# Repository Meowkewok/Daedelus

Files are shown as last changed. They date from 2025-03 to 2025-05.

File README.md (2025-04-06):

# DAEDELUS
Designed by: @Meowkewok
A 3d printer designed by a High School student for Hack Club's Infill.  
## Features
- 310mm3 Print area
- Sherpa Mini Extruder (Direct Drive)
- Under $400
- Heated bed
## Additional Info
Link to Daedelus on the Hack Club Infill site: https://infill.hackclub.com/printers/daedelus/
There is a detailed log with progress and useful info about this in the JOURNAL.MD file  
Link to BOM- https://docs.google.com/spreadsheets/d/1hZlX8M_wxNlEcmAArnw9ARre6T5sTla1MoFUZHyh3DU/edit?usp=sharing  
Link to CAD: https://a360.co/3XCGgpZ   
Thank you so much @dari // alexren for this amazing program!

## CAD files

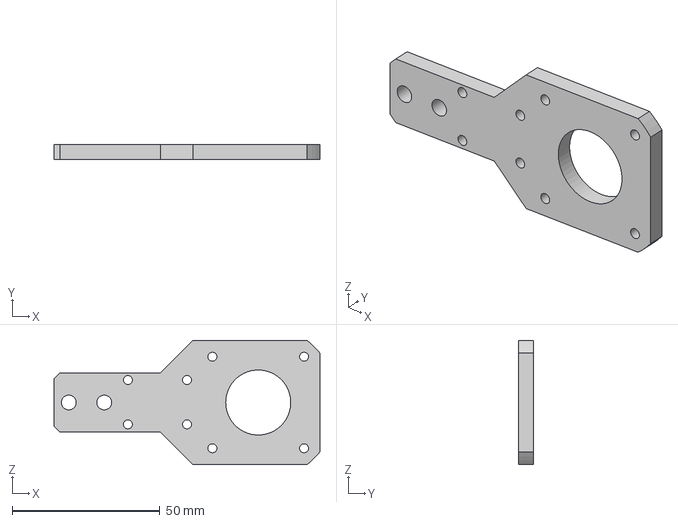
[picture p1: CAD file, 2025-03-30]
CAD/X to Z Mount (NEMA17).step
90.0 x 5.00 x 42.0 mm

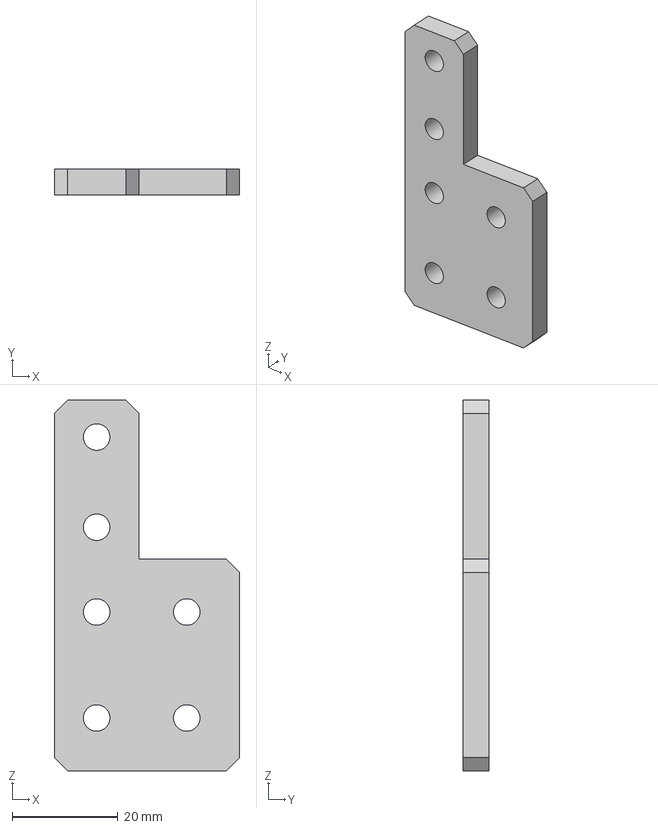
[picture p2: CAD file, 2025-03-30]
CAD/2040 to 2020 Bracket.step
35.0 x 5.00 x 70.0 mm

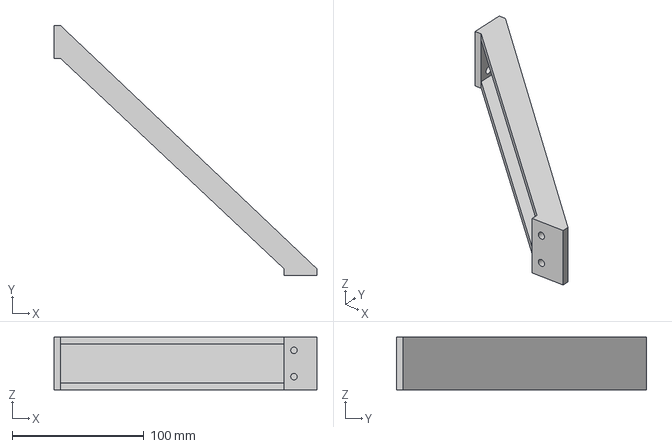
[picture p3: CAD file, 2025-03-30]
CAD/Corner Bracket.step
200.0 x 190.0 x 40.0 mm

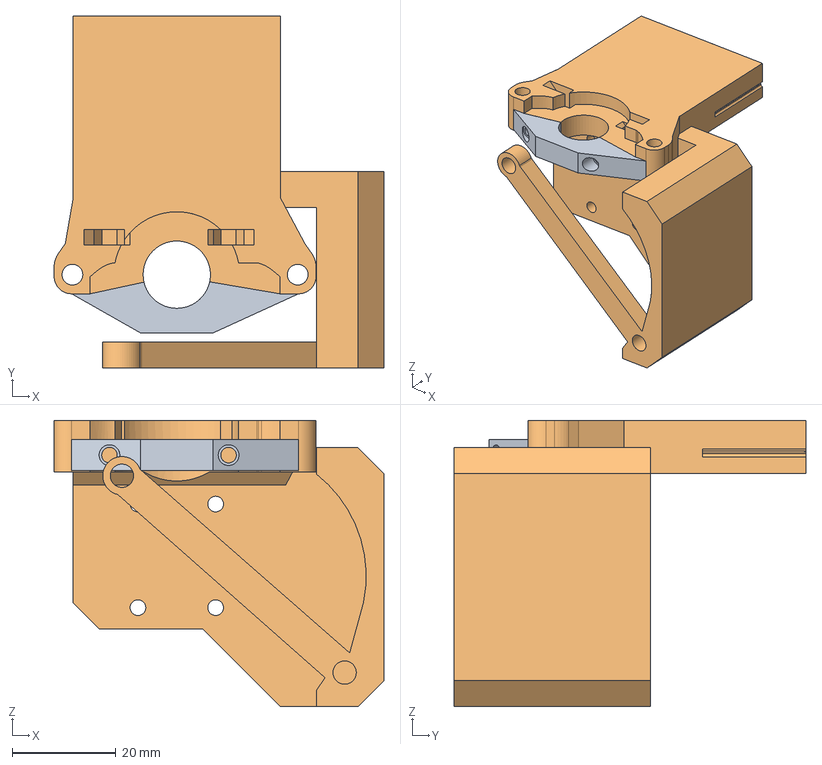
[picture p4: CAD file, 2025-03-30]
CAD/Extruder Mount.step
63.7 x 68.0 x 55.3 mm

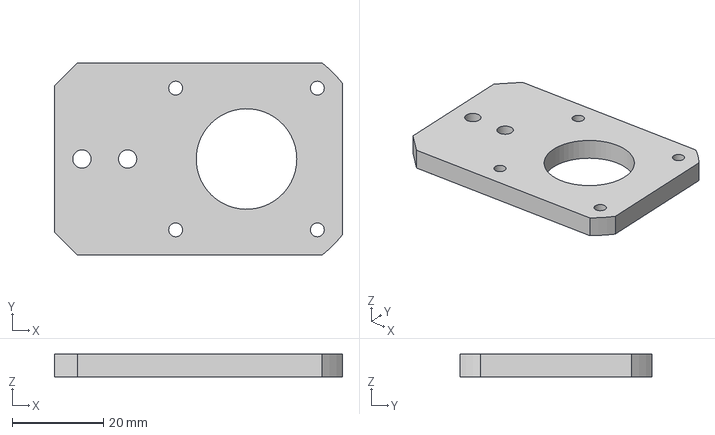
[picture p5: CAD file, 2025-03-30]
CAD/NEMA17 To 20XX Extrusion.step
63.0 x 42.0 x 5.00 mm

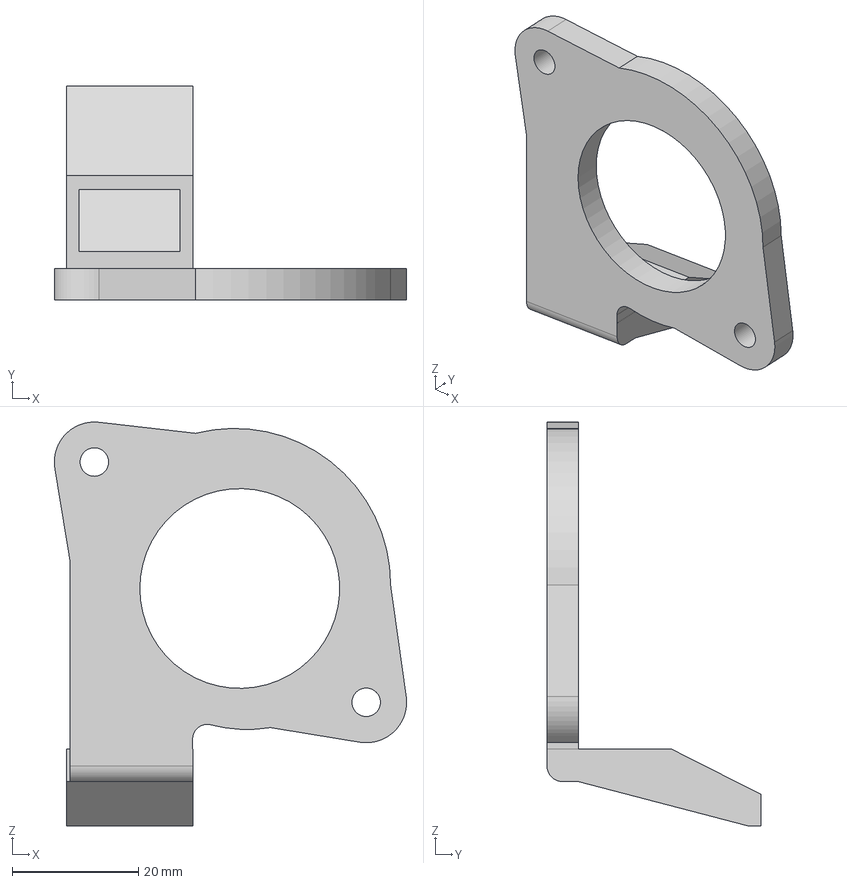
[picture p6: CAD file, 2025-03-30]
CAD/Part Cooling Duct.step
55.7 x 33.9 x 63.9 mm

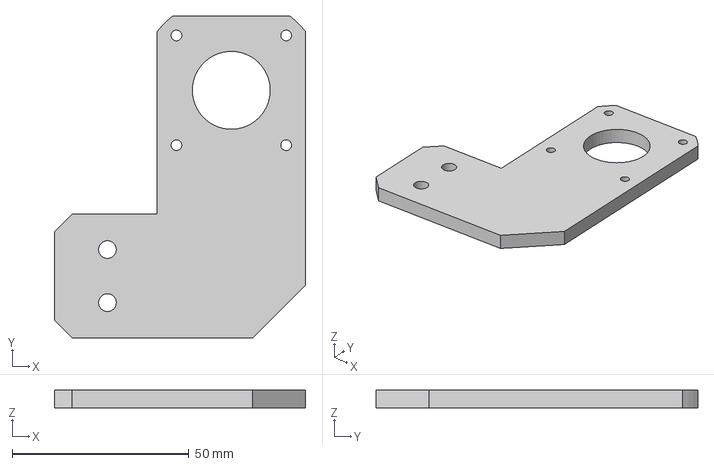
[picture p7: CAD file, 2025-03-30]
CAD/Corner Nema Bracket.step
71.0 x 91.0 x 5.00 mm

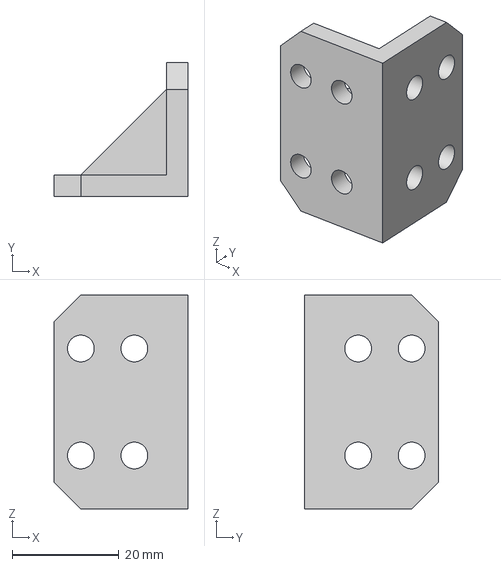
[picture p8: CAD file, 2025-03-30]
CAD/2040 Connection Bracket.step
25.0 x 25.0 x 40.0 mm

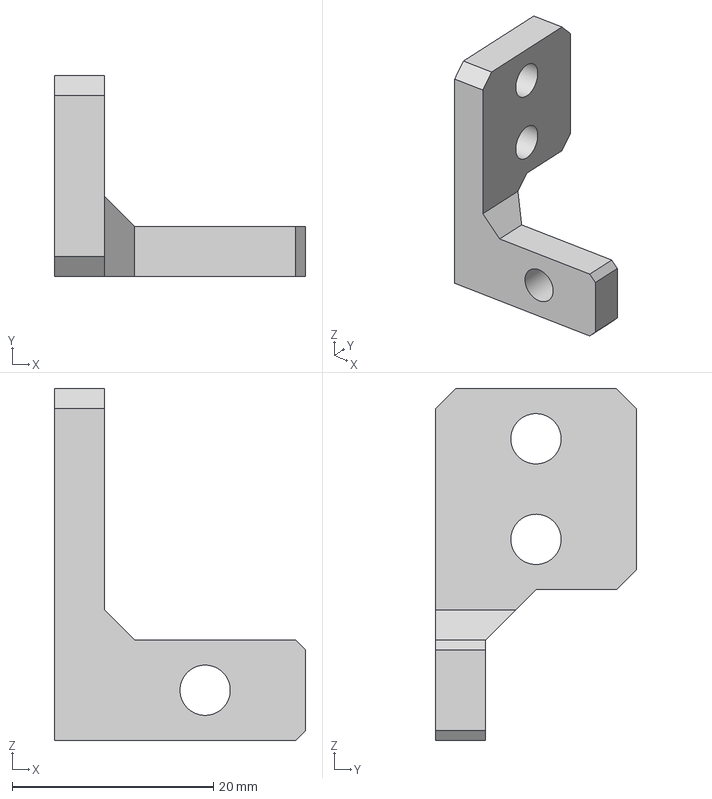
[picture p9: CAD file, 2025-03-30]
CAD/Y Axis Idler Holder.step
25.0 x 20.0 x 35.0 mm

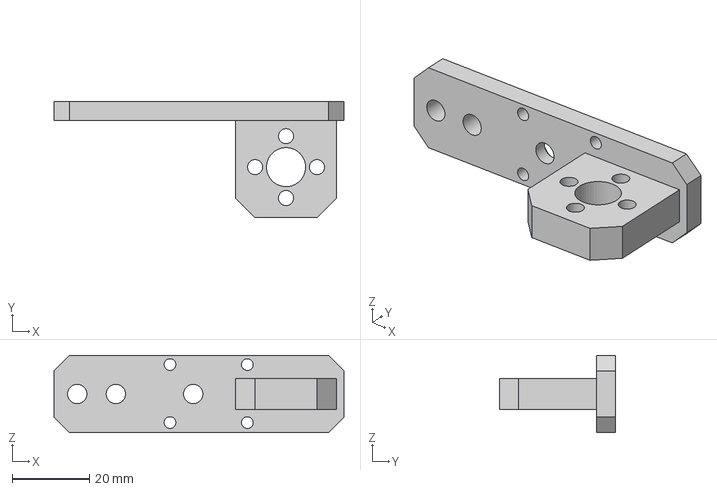
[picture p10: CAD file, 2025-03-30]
CAD/X to Z Mount (Lead Screw).step
75.0 x 30.1 x 20.0 mm

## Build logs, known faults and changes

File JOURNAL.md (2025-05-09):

# Daedelus

Made by: @Meowkewok  
Repository link: https://github.com/meowkewok/Daedelus  
Total hours so far: 42.5   

- [x] I have a 3D printer or will be getting one before March 21st

Daedelus was a Greek inventor, builder, and tinkerer, hence the name.  
I started this project with a coreXY design, but I flew too high, hence the name/designation Daedelus (Icharus) for the first variant.

## Link to CAD: 
https://a360.co/3XCGgpZ

## New Design Goals:
- [x] $400 (USD) (to buy all parts new, w/o shipping or tax)
- [x] 310mm3 Build Volume
- [x] Cartesian Bedslinger
- [x] Cool design
- [x] Touchscreen UI
- [ ] ~~Klipper w/ RPi?~~

## BOM
I just decided to make a spreadsheet using Google Sheets, it was easier. LINK: https://docs.google.com/spreadsheets/d/1hZlX8M_wxNlEcmAArnw9ARre6T5sTla1MoFUZHyh3DU/edit?usp=sharing

## Log
|Date |Task |Time |Notes|
|-----|-----|-----|-----|
|2/21/2025|Set up Repo, ideas, design goals, began BOM, began CAD|4 Hours|Thanks to my brain for finally deciding what to make|
|2/23/2025|CAD, Research|3 hours||
|2/26/2025|Bit more BOM|30 mins|Buying cheap parts from China|
|2/27/2025|Bit more BOM, some research|1 Hour||
|2/28/2025|Tons of CAD!|3 Hours|Finished the XY gantry!, started Z axis/frame|
|3/6/2025|More CAD! Also made a belt routing pic|2 Hour|Worked on frame|
|3/10/2025|BOM|1.5 Hours|Got it down a tad, have more to do...|
|3/15/2025|CAD, Research, BOM|1.5 Hours|Started Redesign|
|3/16/2025|CAD, BOM|3 Hours|Finished XY axis|
|3/17/2025|BOM, CAD|2.5 Hours|Started toolhead mount|
|3/25/2025|CAD|1 Hour|almost done!|
|3/26/2025|CAD|30 mins||
|3/27/2025|CAD, Logo|2 Hours|Yay logo, also almost done again!|
|3/30/2025|CAD, BOM|2 Hours|I think im done!|
|4/3/2025|CAD, Fixing Journal|1 Hour||
|4/5/2025|CAD, Fixing Journal|1 Hour||
|4/6/2025|CAD|2 Hours|Made a toolhead swapper?|
|4/15-18/2025|Ordering parts|5 hours|i hate amazon so much|
|4/21/2025|Got parts, started assembling|4 Hours|YAY PARTS|
|4/22/2025|CAD, Assembly|1 Hour|yay screws|
|4/23/2025|CAD, Assembly|1 hour|made the XY axis|
|5/4/2025|CAD, Assembly|3 hours|I found a problems|
|5/6/2025|Assembling|1 Hour|good progress|

## Detailed Log
3/6/2025  
Last time I was working, I finished the Z-Axis, however, I still need a frame...  
I decided to make the Z axis linear rails and lead screws mirrored, so that the Z axis could be more rigid (not sure if this'l actually help or make it worse, but ChatGPT thought it was a good idea so yea)
  
Need to take a break, but here is progress (after 1 hour):
  
I added some 2020 in an H on both the top and bottom, to help with overall stability and structure.  
Here is the belt routing pic (ik its a bit wonky):
XY Axis Assemby v14  
Not sure if the wonkiness is going to be much of an issue, but I think it may be because the belts are not going in a straight line. I'll see if I can fix it later ig.
  
3/10/2025  
I get my cast off tomorrow!  
I realized that my BOM needs to be cut down, so I started work on that (mostly by trying to find cheaper versions of the parts I am using). OG: ~375, Now: N/A (see next day for why) 
  
3/15/2025  
I made a realization that a coreXY just costs too much for this...  (and it looks horrible)  
Making new goals, and hopefully this time it will work out, and maybe I can make Daedelus (Icharus) in the future. I simply flew too high.
Started work on the CAD for it, looking real good so far, maybe even better than Icharus! I also started working on the BOM for this one, which hopefully will end better than last time.
XZ Axis v3  
  
3/16/2025  
Kept working, here is progress so far:  
XYZ Axis v2  
Continued working on the BOM, and already it is sooo much cheaper!  
This printer is going to use a Klicky, because I looked at the options on aliexpress, and I had been recommended not to use 3dTouch levelers, but real BLtouch levelers cost waaay to much, and the Klicky I chose was only ~$5!  
Using GT2 6mm belts because that seems to be the industry standard, along with T8x8 lead screws. I also am using an anti-backlash nut to hopefully make the Z axis more exact.
Side note- why are 3d printers height Z and not Y? it doesnt really make sense...  
  
3/27/2025  
Did more CAD and made a logo.   
I think this logo looks pretty cool, so another check towards that design goal! I think I am going to put it on the printhead, and maybe on a front plate.    
  
3/30/2025  
I think this CAD model is done!  
XYZ Axis v23  
Going to try to finish the BOM and submit it today!   
As part of my "looking cool" goal, I added some braces that really tie the design in better.  
  
4/3/2025  
I wanted to explain some of the way this printer ended up how it is now. I started by designing a coreXY, and I even finished the CAD, but I realized that there was no chance it would be anywhere near $300, and I didn't really want to spend much of my own money. After a lot of thought, I decided that a way to make it more in-budget would be to redesign it with cheaper parts and as a cartesian, since it would use less parts. The goal for the coreXY was to have a hand-swappable toolhead, but I realized I may not have the budget to even do that on the cartesian. What I am thinking of doing now is designing the swappable toolhead as a "mod" so that I can get the extra $20 to make it (and possibly add a 4th axis?). This whole project is a huge upgrade to what I have now, because I have a printer with 100mm3 of print volume... I do however have access to a bunch of Prusa minis and MK3s at school to print parts on. I wanted to use linear rails because I want this to be as rigid as possible, for if I make a swappable toolhead.    
Since one of my goals was to make it look cool, I updated the design of the fan shroud. I also made different parts different colors.   
Another edit I had to make was moving the fan duct around a little bit, since in its original position it would interfere with the print.  
XYZ Axis Angle 26  
XYZ Axis v26  
I also want to mention that I decided to use a Sherpa Mini as the extruder. This is because I wanted to have a direct drive extruder for possible TPU/Flexibles use. I chose a V6 hotend because they are cheap and pretty readily avaliable. I am using the BTT SKR mini because Daedelus only needs 4 motors, and it fits pretty well into the budget. I am going to scrounge a PSU, because it costs quite a bit to buy straight out.  
  
4/5/2025  
I started today working on a CAD prototype of the Hotswap mechanism. I wanted it to be hand operated, not done by the printer itself, because it allows the mechanism to be much simpler. I think this is what I am going to use the PCB for, since I need a way of transferring power and data to the printer without directly connecting to each hotend, so that I could have multiple hotend/extruder combos without having to unplug/replug wires or get a bigger control board. The design is heavily influenced by the WhamBam Mutant. (check it out, it is pretty cool, here is an article about it: https://toms3d.org/2021/01/21/whambam-mutant-a-quick-change-toolhead-upgrade-for-any-3d-printer-not-on-kickstarter/  
Using a TFT-35 from BTT because I really have some strange affinity for touchscreen items, so why not include one in my printer! I was considering using a RPi running KlipperScreen, but I think that even just marlin firmware may be enough. I do have a pi at home, so I may add that functionality later, but I have it set aside for another possible project I hope to make soon.  

4/6/2025  
Worked on a toolhead swapper, it is kinda hard to see on the main model, so here is a pic of just the toolswapper. (each part is a different color for ease of vision)
Hotswap Assembly Side 1  
Hotswap Assembly side 2  
As I mentioned yesterday, it is based on the WhamBam Mutant. To remove the toolhead, all you do is pull the lever, which will force the toolhead off.
    
4/21/2025  
Got my parts WOO  
!  

## OLD DESIGN INFO (Icharus)  

### (OG) Design goals: 
- [x] CoreXY
- [x] 300 x 300 x 250 (at least) mm Build area
- [ ] Swappable toolhead (maybe magnets?)
- [ ] Very rigid
- [ ] Under $500
- [ ] Looks cool

### (OG) BOM
BOM Total: ~$375 (needs to be cut down)
|Parts |Quantity |Cost (per) |Link  |Total Cost| 
|---|---|---|---|---|
|Linear Rails + Carriages|5|$16 (less if on sale) |https://www.aliexpress.us/item/3256804722090559.html?gatewayAdapt=glo2usa|$80|
|Extruder Assembly|1|$0|Have on hand (from Ender 3)|$0|
|NEMA 17 Steppers|5|$40-$70|https://www.aliexpress.us/item/3256802068491329.html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|$40-70|
|Threaded rods|2|$5|https://www.aliexpress.us/item/2251832687660623.html?gatewayAdapt=glo2usa4itemAdapt|$10|
|BTT Octopus (Mainboard)|1|$45|https://www.aliexpress.us/item/3256806125317618.html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, https://biqu.equipment/products/bigtreetech-octopus-v1-1?variant=39749194023010|$45|
|T-Nuts for Extrusion|Lots|$1-5|https://www.aliexpress.us/item/2251832673603903.html?gatewayAdapt=glo2usa4itemAdapt|$15|
|Power Supply|1|$45|https://www.aliexpress.us/item/2255800177960035.html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|$45|
|Aluminum Extrusion|TBD|<$10|https://www.aliexpress.us/item/3256802466647592.html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|$60|
|GT2 Belt + Idlers + Pulley|2|$2|https://www.aliexpress.us/item/3256805425039875.html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|$4|
|Lead Screw Coupler|2|$2.5|https://www.aliexpress.us/item/3256806935585490.html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,scm-url:1007.40050.354490.0,pvid:4129a269-8bff-4c93-a41d-8f3881bd4cf1,tpp_buckets:668%232846%238110%231995&pdp_ext_f=%7B%22order%22%3A%221066%22%2C%22eval%22%3A%221%22%2C%22sceneId%22%3A%2230050%22%7D&pdp_npi=4%40dis%21USD%212.53%210.99%21%21%2118.30%217.21%21%40%2112000039472281805%21rec%21US%21%21ABX&utparam-url=scene%3ApcDetailBottomMoreOtherSeller%7Cquery_from%3A|$5|
|M3/M4/M5 bolts + nuts|1|$12|https://www.aliexpress.us/item/3256805690668398.html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||
|4x2 Magnets|1|$1|https://www.aliexpress.us/item/3256807003208737.html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|$1|
|Anti-Backlash nut|2|$1|https://www.aliexpress.us/item/3256804076887678.html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|$2|
|GT2 Idlers (6pcs)|1|$4|http://aliexpress.us/item/3256807371672860.html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|$4|
|plastic|all of it|like $20 per kilo|Obtain from school's makerspace?|

### (OG) Ideas for Attachments:
- 3d Extruder (obviously)
- Dremel/CNC head
- 4-Axis attachment - adds a 4th axis which can be attached to by various toolheads
- Laser (DANGER!)
- Pen plotter

### Credits:  
Thank you to:  
- Rabbi Hametz (RTH) for letting me use school printers and stuff
- Ryan Rich for giving me random ender 3 parts

### Fun stories:
- This printer is being designed with a broken finger (at the beginning at least. Its healed now!)
- Realized I had to redesign the printer half way through since I would never be able to make it affordable enough.
